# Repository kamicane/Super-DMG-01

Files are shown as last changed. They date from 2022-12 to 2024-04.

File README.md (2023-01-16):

# Super DMG-01

A [KiCad](https://www.kicad.org/) 6.0 recreation of the original Game Boy, with a few modern twists.

One of the main goals of this project is to build an entire DMG using only a DMG CPU or a SGB CPU.

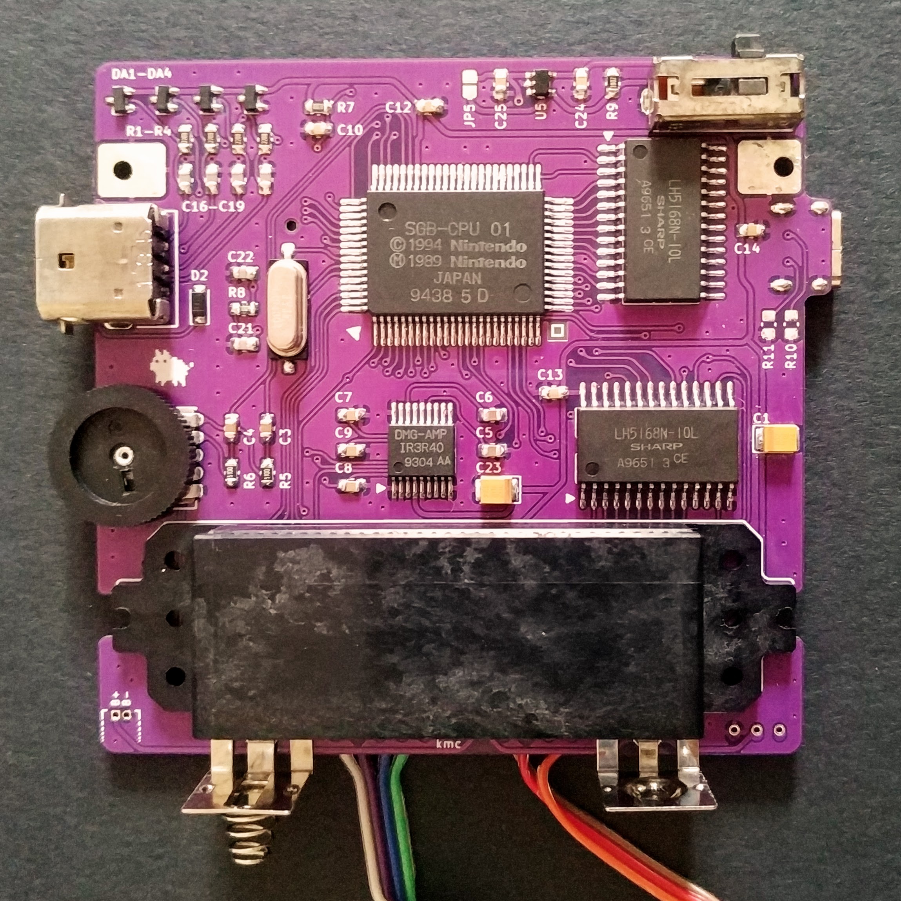
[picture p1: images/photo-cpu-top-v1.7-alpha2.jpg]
pcb-v1.3
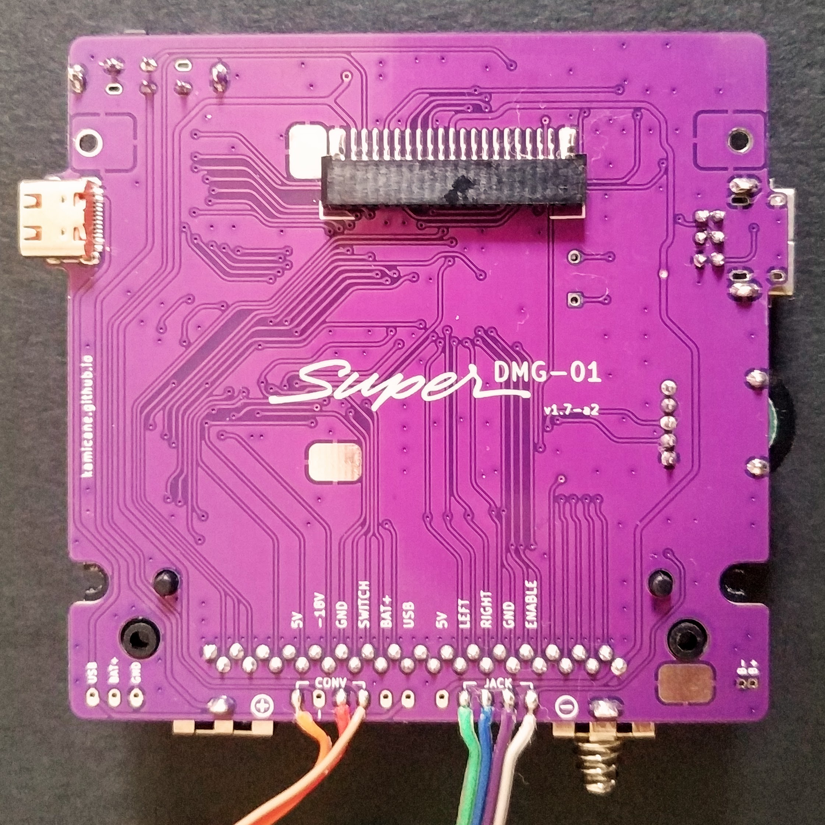
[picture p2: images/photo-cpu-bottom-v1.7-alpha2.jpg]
usb-v1.3
 

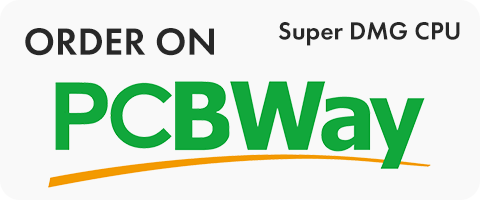
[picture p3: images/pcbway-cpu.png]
pcbw
[](https://www.pcbway.com/QuickOrderOnline.aspx?projectid=13266&issmt=0)
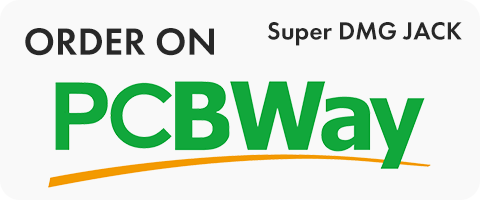
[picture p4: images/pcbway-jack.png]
pcbway
[](https://www.pcbway.com/QuickOrderOnline.aspx?projectid=13350&issmt=0)
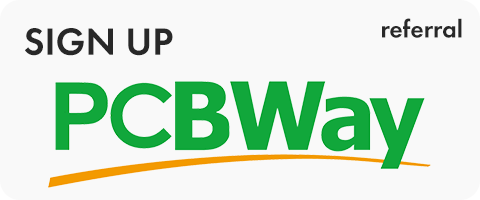
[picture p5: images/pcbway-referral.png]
pcbway
[](https://pcbway.com/g/Gw03Yt)

## Credits

- bit9 for the [DMG schematics](https://imgur.com/a/X5qKI) and [board scans](https://chipmusic.org/forums/post/215957/#p215957)
- [Gekkio](https://github.com/Gekkio) for the CPU, RAM, CART symbols from [Gekkio KiCad libs](https://github.com/Gekkio/gekkio-kicad-libs)
- [Wesk](https://bitbuilt.net/forums/index.php?members/wesk.1486/) for [these amazing DMG shell scans](https://bitbuilt.net/forums/index.php?threads/dmg-gameboy-scan.4479/), which allow me to do all sort of adapters and covers and whatnot, and test the pcb fitment virtually

## Boards

Like an original DMG, the Super DMG-01 is made out of separate boards. Doumentation for each board can be found in the relative sub-folders:

- CPU Board: [Super DMG CPU](super-dmg-cpu)
- JACK Board: [Super DMG JACK](super-dmg-jack)

## 3rd party boards

To complete the game boy additional boards are required:

- DC CONV Board: use [MouseBiteLabs](https://github.com/MouseBiteLabs)' [DMGC-PWR-01](https://github.com/MouseBiteLabs/Game-Boy-DMG-Color/tree/main/DMGC-PWR-01) or use one from a DMG
- LCD Board: Use any of the available IPS kits or use one from a DMG

## Disclaimer

I am not an electronics expert. Super DMG-01 might fry your games, set your house on fire and kill your pets.

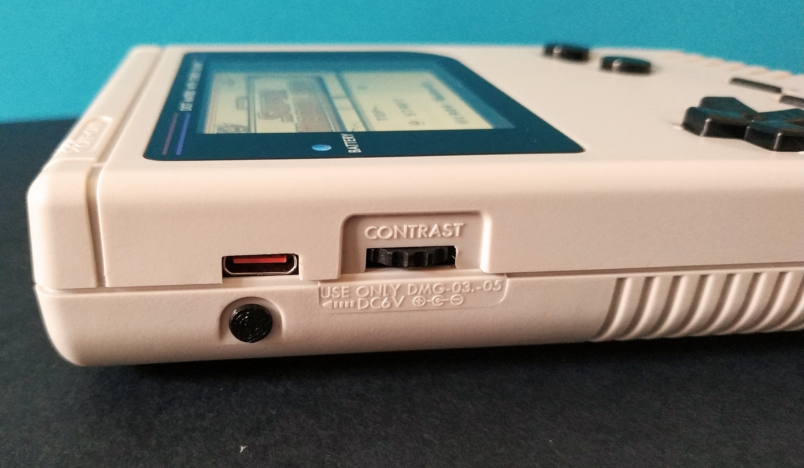
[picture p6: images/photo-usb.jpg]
bottom


## License

This work is licensed under the [Creative Commons Attribution-ShareAlike 4.0 International License.](http://creativecommons.org/licenses/by-sa/4.0/)

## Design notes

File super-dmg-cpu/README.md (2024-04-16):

# Super DMG CPU

Super DMG CPU works with both IPS and DOT MATRIX LCD boards.

top bottom

## Credits

The schematic is largely based on [the work done by bit 9](https://imgur.com/a/X5qKI).

I used [Gekkio KiCAD libs](https://github.com/Gekkio/gekkio-kicad-libs) for a few symbols (cpu, ram, cart connector, link port). The specialized footprints were traced by me using fusion 360, using these [scans by bit 9](https://chipmusic.org/forums/topic/13608/dmg-main-board-schematic-circuit-arduinoboy/) as a reference.

## Warning

v1.8 and below have an error with the Link Port, where the footprint was flipped (sigh). If you have a v1.8 or below please don't use the link port, as it might damage the other Game Boy! This was fixed in later versions.

## Features

### Compatibility

Super DMG CPU can be built using new components, except for the CPU, power switch and link connector. It is also possible to use some components harvested from a DMG.

### USB Type-C

The round power connector is replaced with an USB Type-C port. The port is only connected to a pad on the motherboard, you need to add your own battery charger and/or power regulator if you want to make use of it. This port is optional.

### Power distribution IC

A power distribution IC takes the system load away from the power switch, so the game boy remains fully operational even if the switch is not in an optimal condition. This circuit can be bypassed with a jumper.

### Internal ProSound

The headphone output does not pass through the amplifier, only the volume potentiometer.

## BOM

| Designator | Package | Qty | Value / Description | Source |
|---|---|-----|---|---|
| U1 | QFP-80 14x20 p0.8 | 1 | CPU | DMG, SGB
| U2 | SOP-28 17.5x8.4 p1.27 | 1 | VRAM | DMG, SGB, [LCSC](https://lcsc.com/product-detail/C1351073.html)
| U3 | SOP-28 17.5x8.4 p1.27 | 1 | RAM | DMG, SGB, [LCSC](https://lcsc.com/product-detail/C1351073.html)
| U4 | SSOP-18 6x7.4 p0.8 | 1 | Audio Amplifier | DMG
| EXT1 | | 1 | Link Connector | DMG
| DA1, DA2, DA3, DA4 | SOT-23-3 | 4 | BAV99-7-F | [LCSC](https://www.lcsc.com/product-detail/C106919.html)
| C1, C23 | 3528 | 2 | 100µf tantalum | [LCSC](https://lcsc.com/product-detail/C122271.html)
| SW1 | | 1 | Power Switch | DMG
| U5 | SOT-23-5 | 1 | Power Distribution | [LCSC](https://lcsc.com/product-detail/C517266.html)
| D2 | SOD-123 | 1 | 1N414 | [LCSC](https://lcsc.com/product-detail/C83528.html)
| X1 | HC-49S | 1 | 4.194304 MHz | DMG, [LCSC (TH)](https://lcsc.com/product-detail/C718646.html), [LCSC (SMD)](https://lcsc.com/product-detail/C2149317.html)
| USB1 | USB_C_16p | 1 | Charge Connector | [LCSC](https://lcsc.com/product-detail/C2931472.html)
| VR1 | | 1 | Volume Pot | DMG, [AliExpress](https://www.aliexpress.com/item/32840044311.html)
| CN1 | 1.25 x 21 SMD | 1 | LCD Board Connector | DMG, [AliExpress](https://www.aliexpress.com/item/1005005484837763.html)
| CN2 |  | 1 | Cart Connector | DMG, [AliExpress](https://www.aliexpress.com/item/1005002719771295.html)
| CN3 | | 1 | AA Battery Contacts | DMG, [AliExpress](https://www.aliexpress.com/item/32801068366.html)
| CN4 | 1.25 TH | 1 | Lipo Battery Connector | [LCSC](https://www.lcsc.com/product-detail/C722595.html)
| C3, C4 | 0805 | 2 | 1µF |
| C5, C6 | 0805 | 2 | 10µF |
| C7, C8, C9 | 0805 | 3 | 47nF |
| C10, C24, C25 | 0805 | 3 | 100nF |
| C12, C13, C14 | 0805 | 3 | 10nF |
| C16, C17, C18, C19 | 0805| 4 | 100pF |
| C21, C22 | 0805 | 2 | 27pF |
| R1, R2, R3, R4 | 0805 | 4 | 220Ω|
| R5, R6 | 0805 | 2 | 510Ω |
| R7 | 0805 | 1 | 180kΩ |
| R8 | 0805 | 1 | 1MΩ |
| R9 | 0805 | 1 | 10kΩ |
| R10, R11 | 0805 | 2 | 5.1kΩ |

## Assembly

- Solder all SMD components on the front side
- If using a power board with integrated power distribution close ```J5``` and do not install ```U5```, ```C24```, ```C25```, ```R9```
- If using an external amplifier, such as [Super DMG JACK](../super-dmg-jack) do not install ```U4```, ```C5-C9```, ```C23```
- If you do not need link functionality you can omit ```EXT1```, ```DA1-DA4```, ```R1-R4```, ```C16-C19```, ```D2```
- Solder the through hole components and the LCD board connector
- (Optional) solder the usb connector and cut an opening for the usb port in the front shell using the provided [rudimentary jig](../3d_models/dmg_usbc_jig.stl)
- The original DC jack hole can be covered with this simple [3d printed plug](../3d_models/dmg_dc_plug.stl)

## Notes

If using an original LCD board you need an original *DMG DC CONV* voltage regulator, as acceptable modern replacements that also include the -18v rail *do not exist yet*.

This pcb cannot be easily biverted yet.

## Ordering

[pcbway](https://www.pcbway.com/QuickOrderOnline.aspx?projectid=13266&issmt=0)
[pcbway](https://pcbway.com/g/Gw03Yt)

Make sure you order with 1.0mm thickness.

## License

This work is licensed under the [Creative Commons Attribution-ShareAlike 4.0 International License.](http://creativecommons.org/licenses/by-sa/4.0/)

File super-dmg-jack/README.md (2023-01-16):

# Super DMG JACK

Super DMG JACK is a replacement headphone/audio PCB for the original Game Boy. It can be used on a stock DMG or the Super DMG-01.

It uses a PAM8302 mono amplifier to power the speaker when no headphones are present, but it can also be built as a headphone jack replacement using the amplifier on the CPU board.

The amplifier schematic is based on [Adafruit's pam8302 amplifier PCB](https://github.com/adafruit/Adafruit-PAM8302-Mono-Amplifier-PCB).

The headphone output needs to be unamplified, and grabbed _after_ the DMG volume potentiometer.

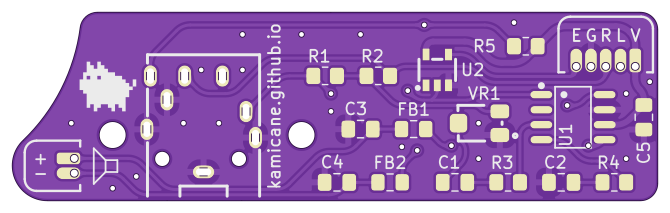
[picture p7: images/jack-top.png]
sdmg jack top
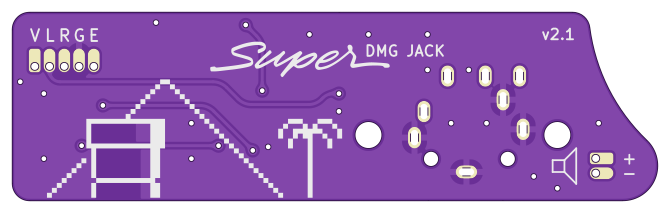
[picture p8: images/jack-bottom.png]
sdmg jack bottom
 

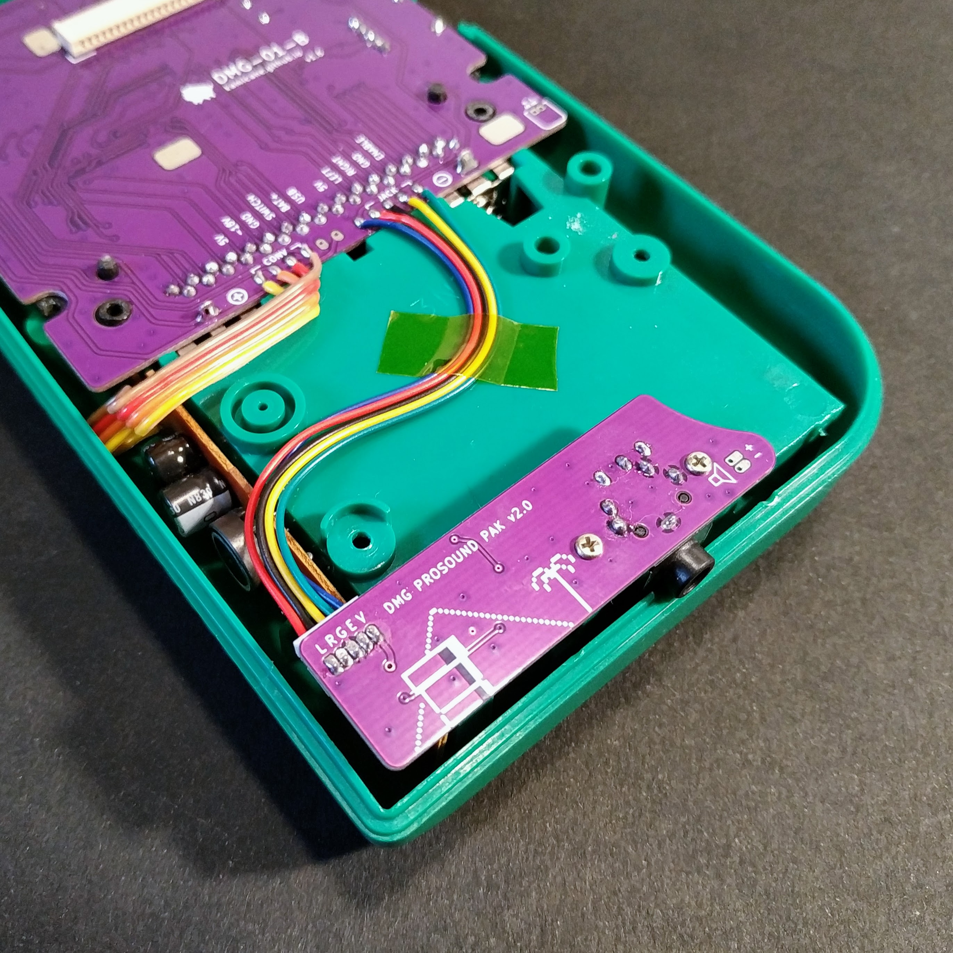
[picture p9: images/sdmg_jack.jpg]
sdmg jack
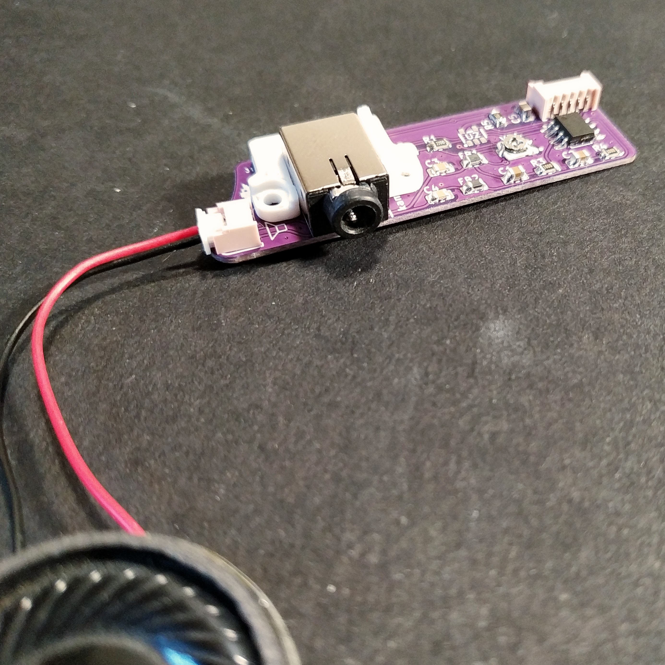
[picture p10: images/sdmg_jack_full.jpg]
sdmg jack full
 

## BOM

| Designator | Package | Qty | Value / Description | Source |
|---|---|-----|---|---|
| CN1 | PJ-3043-B | 1 | Headphone connector | [LCSC](https://lcsc.com/product-detail/C2682182.html) |
| CN2 | 1.25 TH | 1 | CPU PCB Connector | [LCSC](https://lcsc.com/product-detail/C722595.html) |
| CN3 | 1.25 TH | 1 | Speaker Connector | [LCSC](https://lcsc.com/product-detail/C722604.html) |
| U1 | SOP-8 | 1 | PAM8302 | [LCSC](https://lcsc.com/product-detail/C112137.html) |
| U2 | SOT-23-5 | 1 | SN74AHC1G14 | [LCSC](https://lcsc.com/product-detail/C7469.html) |
| VR1 | Bourns TC33X-2-103E | 1 | 10kΩ SMD | [LCSC](https://lcsc.com/product-detail/C719176.html) |
| FB1, FB2 | 0805 | 2 | Ferrite Bead ||
| C1, C2, C5 | 0805 | 3 | 1µf ||
| C3, C4 | 0805 | 3 | 220pf ||
| R1, R2 | 0805 | 2 | 220Ω ||
| R3, R4 | 0805 | 2 | 100Ω ||
| R5 | 0805 | 1 | 10kΩ ||

I got premade wires from [AliExpress](https://www.aliexpress.com/item/1005002353691025.html) (1.25mm 2p and 5p), but you can also just use 28/30 awg without connectors.

I use "WSC" 8Ω 2W speakers from AliExpress.

## DMG Pinout

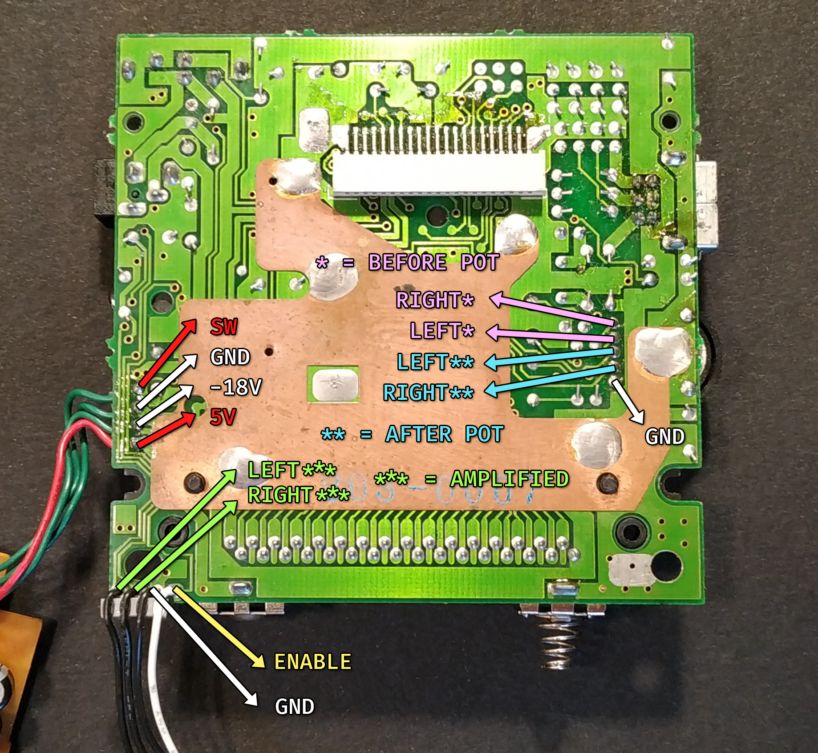
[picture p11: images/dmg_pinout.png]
dmg-pinout


## Full Installation

Important: do not solder ```U2``` and/or do not wire the (E)nable signal. The speaker must be connected to this board.

- Solder the SMD components
- Solder the through hole components
- On the stock DMG solder the L/R signals to the volume potentiometer (** after pot), on Super DMG-01 solder to the bottom pads directly
- Get power from the 5v rail on the CPU board
- Adjust the trimpot

### Trimpot notes

Adjust the trimpot to reduce the power draw and max volume of the amplifier. Boot the DMG at minimum volume, and slowly turn it up, while also adjusting the trimpot. The Game Boy will shut down if you're drawing too much power.
Do the final trimpot adjustment once the DMG volume is at its maximum value.

The final maximum volume will depend on the batteries and the voltage regulator you're using.

## Jack-only Installation

The jack-only installation is meant to be used with the on-board DMG amplifier, however you still need to solder an extra wire for power as the ENABLE signal needs to be inverted.

Important: solder only ```U2```, ```R5```, the headphone jack and the CPU PCB connector. The speaker must be kept in the LCD board.

- Solder the SMD components
- Solder the through hole components
- On the stock DMG solder the L/R signals to the volume potentiometer (** after pot), on Super DMG-01 solder to the bottom pads directly
- Get power from 5V (Super DMG CPU) or SW (stock DMG) on the CPU board

## Notes

3d print the [jack spacer](../3d_models/super_dmg_jack_spacer.stl) for correct alignment.

## Ordering

[pcbway](https://www.pcbway.com/QuickOrderOnline.aspx?projectid=13350&issmt=0)
[pcbway](https://pcbway.com/g/Gw03Yt)

Make sure you order in 1.0mm thickness.

## License

This work is licensed under the [Creative Commons Attribution-ShareAlike 4.0 International License.](http://creativecommons.org/licenses/by-sa/4.0/)

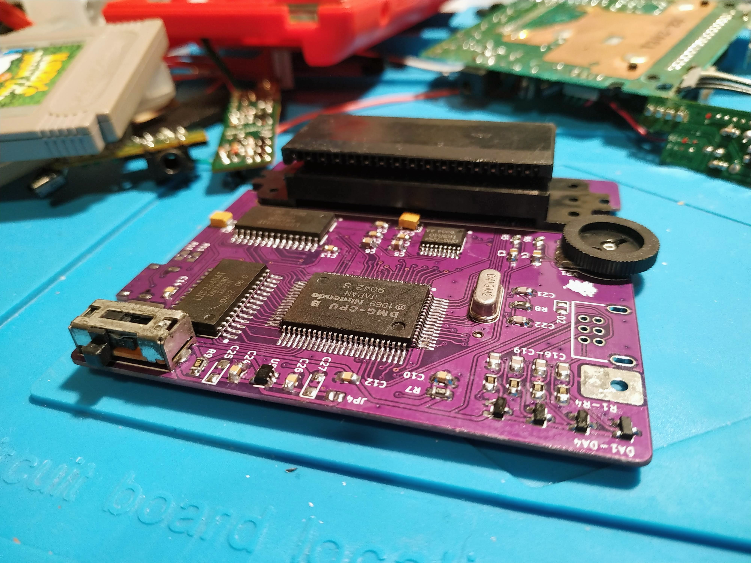
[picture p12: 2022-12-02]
images/pcb-v1.3.jpg

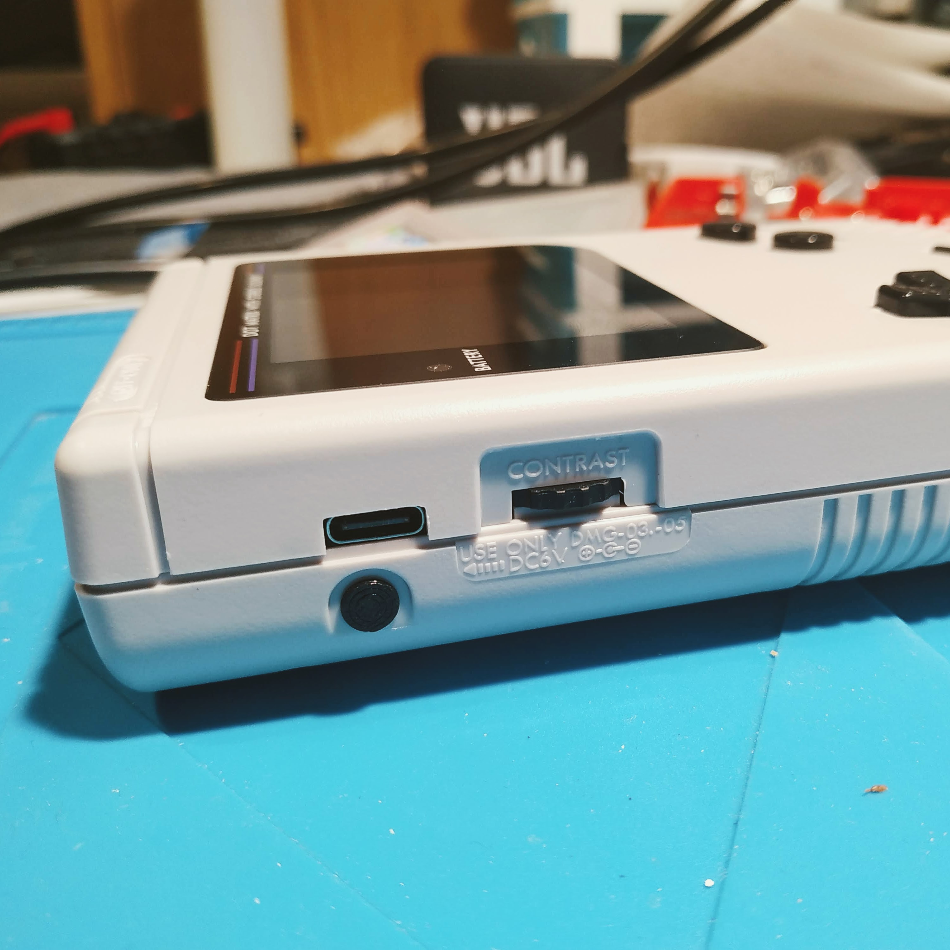
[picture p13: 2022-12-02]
images/usb-v1.3.jpg

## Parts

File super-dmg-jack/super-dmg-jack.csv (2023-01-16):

Comment | Designator | Footprint | LCSC
1µf | C1,C2,C5 | Capacitor_SMD:C_0805_2012Metric_Pad1.18x1.45mm_HandSolder
220pf | C3,C4 | Capacitor_SMD:C_0805_2012Metric_Pad1.18x1.45mm_HandSolder
PJ-3043-B | CN1 | easyeda2kicad:AUDIO-TH_PJ-3043-B | C2682182
DMGB_AUDIO_HEADER | CN2 | kmc_lib:CONN-TH_5P-P1.25_LONGPADS | C722604
Speaker | CN3 | kmc_lib:CONN-TH_2P-P1.25_HCTL_HC-1.25-2AW_LONGPADS | C722595
FerriteBead_Small | FB1,FB2 | Inductor_SMD:L_0805_2012Metric_Pad1.15x1.40mm_HandSolder
220Ω | R1,R2 | Resistor_SMD:R_0805_2012Metric_Pad1.20x1.40mm_HandSolder
100Ω | R3,R4 | Resistor_SMD:R_0805_2012Metric_Pad1.20x1.40mm_HandSolder
10kΩ | R5 | Resistor_SMD:R_0805_2012Metric_Pad1.20x1.40mm_HandSolder
PAM8302AADCR | U1 | easyeda2kicad:SOP-8_L4.9-W3.9-P1.27-LS6.0-BL | C112137
SN74AHC1G14DBVR | U2 | easyeda2kicad:SOT-23-5_L3.0-W1.7-P0.95-LS2.8-BR | C7469
TC33X-2-103E | VR1 | easyeda2kicad:RES-ADJ-SMD_3P-L3.0-W3.8-P1.75-BR | C719176

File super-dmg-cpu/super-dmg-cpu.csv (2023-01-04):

Comment | Designator | Footprint | LCSC
100µf | C1,C23 | Capacitor_Tantalum_SMD:CP_EIA-3528-12_Kemet-T_Pad1.50x2.35mm_HandSolder | C122271
100nF | C10,C24,C25 | Capacitor_SMD:C_0805_2012Metric_Pad1.18x1.45mm_HandSolder | C49678
10nF | C12,C13,C14 | Capacitor_SMD:C_0805_2012Metric_Pad1.18x1.45mm_HandSolder | C1710
100pF | C16,C17,C18,C19 | Capacitor_SMD:C_0805_2012Metric_Pad1.18x1.45mm_HandSolder | C1790
27pF | C21,C22 | Capacitor_SMD:C_0805_2012Metric_Pad1.18x1.45mm_HandSolder | C527182
1µF | C3,C4 | Capacitor_SMD:C_0805_2012Metric_Pad1.18x1.45mm_HandSolder | C28323
10µF | C5,C6 | Capacitor_SMD:C_0805_2012Metric_Pad1.18x1.45mm_HandSolder | C15850
47nF | C7,C8,C9 | Capacitor_SMD:C_0805_2012Metric_Pad1.18x1.45mm_HandSolder | C53134
BATTERY | CN4 | easyeda2kicad:CONN-TH_2P-P1.25_HCTL_HC-1.25-2AW | C2845535
1N414 | D2 | Diode_SMD:D_SOD-123 | C83528
BAV99-7-F | DA1,DA2,DA3,DA4 | kmc_lib:SOT-23-3_L2.9-W1.3-P1.90-LS2.4-BR | C106919
220Ω | R1,R2,R3,R4 | Resistor_SMD:R_0805_2012Metric_Pad1.20x1.40mm_HandSolder | C17557
5.1kΩ | R10,R11 | Resistor_SMD:R_0805_2012Metric_Pad1.20x1.40mm_HandSolder | C27834
510Ω | R5,R6 | Resistor_SMD:R_0805_2012Metric_Pad1.20x1.40mm_HandSolder | C17734
180kΩ | R7 | Resistor_SMD:R_0805_2012Metric_Pad1.20x1.40mm_HandSolder | C17501
1MΩ | R8 | Resistor_SMD:R_0805_2012Metric_Pad1.20x1.40mm_HandSolder | C17514
10kΩ | R9 | Resistor_SMD:R_0805_2012Metric_Pad1.20x1.40mm_HandSolder | C17414
DPDT | SW1 | kmc_lib:DMGB_POWER_SWITCH | C2848866
LPW5209B5F-21 | U5 | easyeda2kicad:SOT-23-5_L2.9-W1.6-P0.95-LS2.8-BL | C517266
CHARGE_PORT | USB1 | kmc_lib:USB_C_16p | C319148
4.194304 MHz | X1 | dmg_lib:HC-49S | C2149317

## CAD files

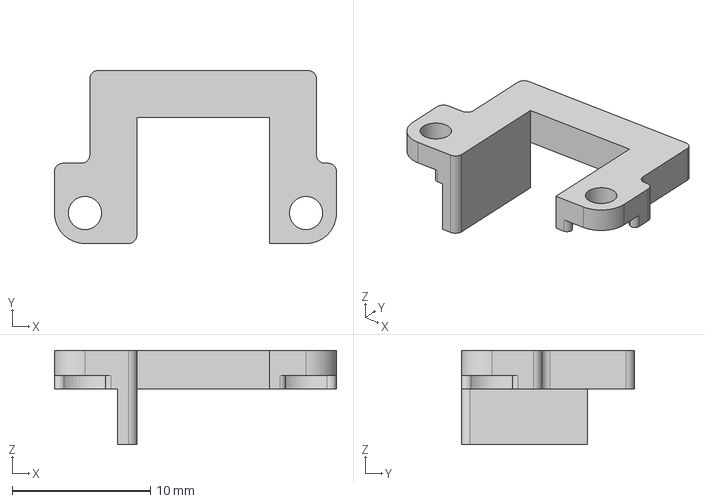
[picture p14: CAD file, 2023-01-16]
3d_models/super_dmg_jack_spacer.step
20.4 x 12.5 x 6.80 mm

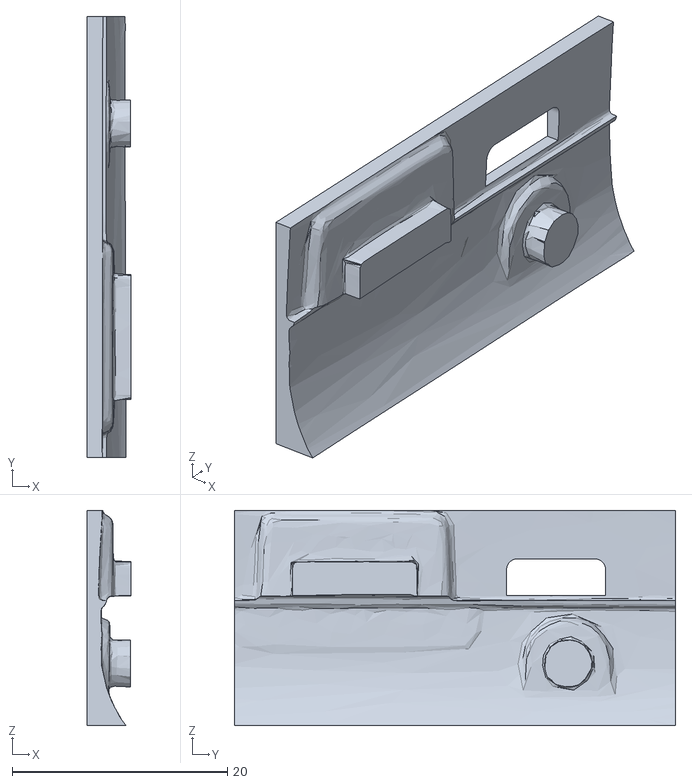
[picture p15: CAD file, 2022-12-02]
3d_models/dmg_usbc_jig.stl
4.12 x 41.0 x 20.0

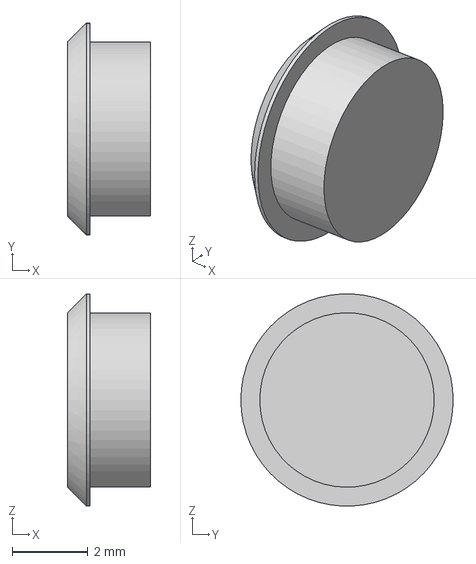
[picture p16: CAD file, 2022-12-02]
3d_models/dmg_dc_plug.step
2.20 x 5.60 x 5.59 mm

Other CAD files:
3d_models/dmg_dc_plug.stl
3d_models/super_dmg_jack_spacer.stl

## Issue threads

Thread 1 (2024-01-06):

Fix port Link ?

Neorad1870, 2024-01-06:
Hello, I would like to know if a solution would be possible to correct the communication port? with track cut? welding ? I have version 1.8r, thank you

rapiqui, 2024-01-23:
Hi, perhaps a thin intermediate pcb with wire rerouting? I am in the same situation. Thanks!

Neorad1870, 2024-01-23:
Super GameBoy Link Port by qwertymodo on Tindietindie.comJoão ***@***.***+41 76 405 17 36Le 23 janv. 2024 à 16:57, rapiqui ***@***.***> a écrit :Hi, perhaps a thin intermediate pcb with wire rerouting? I am in the same situation. Thanks!

EthanChinCN, 2024-01-24:
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

credit to zipplet from gameboy discord server.

explit7, 2024-05-18:
Hm, i also have 1.8R Mainboard. I will simply solder 6x 90degree pins. A simple adapter could be made externally.
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

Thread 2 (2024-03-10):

LCD board connector no longer available from link

Q-Bert-Reynolds, 2024-03-10:
[The LCD connector Ali Express link in the build of materials](https://github.com/kamicane/Super-DMG-01/blob/e557c3cb3f4540ce3f1007be29782819fd7b3acc/super-dmg-cpu/README.md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) is dead. Almost felt like I caused it. It wasn't dead until after I ordered a few and nothing came. I've been looking for another source, but I've had no such luck.

Q-Bert-Reynolds, 2024-03-13:
I found a potentially suitable replacement for the [LCD board connector here](https://www.aliexpress.us/item/3256805298523011.html). They have an option for a 21 pin FPC connector with 1.25mm spacing that looks the part. I'm ordering a few now. I'll let you know how it goes.

On a related note, I found an okay-ish replacement for the [power switch from Mouser](https://www.mouser.com/ProductDetail/CK/SK22F02G6?qs=Gufeu08L/l3k5gmurXhV/g%3D%3D). It has the same footprint, but it requires quite a bit of trimming to fit - removing two of the pins, shortening the metal housing by 3mm or so, and shaving down the plastic slide so that it can fit in the switch cover plate thing. Still looking for a low profile version though.

kamicane, 2024-03-21:
> I found a potentially suitable replacement for the [LCD board connector here](https://www.aliexpress.us/item/3256805298523011.html). They have an option for a 21 pin FPC connector with 1.25mm spacing that looks the part. I'm ordering a few now. I'll let you know how it goes.

Amazing!

As for the power switch another idea could be finding a smaller one and making a 3d printed replacement part to fit it in the shell. Should be fine as long as it lines up somewhat.

Q-Bert-Reynolds, 2024-04-15:
Completely forgot to follow up. I can confirm that the connector they sent fits and works.

kamicane, 2024-04-16:
Updated the link, thanks!

explit7, 2024-06-06:
Unfortunately they don't ship to Germany, maybe to some other countries also.
 https://www.aliexpress.us/item/3256805298523011.html

If you find another seller, who sells the display connector - it would be really cool!

itavero, 2024-12-31:
@explit7 Did you find a supplier yet? Also looking for these and the provided links do not work for me in the Netherlands.

explit7, 2024-12-31:
> @explit7 Did you find a supplier yet? Also looking for these and the provided links do not work for me in the Netherlands.

Unfortunately not. I had to sacrifice a Mainboard in bad condition. for me the links also not work anymore... :(

Closed 2024-04-16.

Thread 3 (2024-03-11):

audio amplifier assembly on original dmg

Neorad1870, 2024-03-11:
hello, would it be possible to have a photo of the assembly concerning the audio amplifier on an original dmg, I do not fully understand the explanations, thank you

kamicane, 2024-03-21:
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

Install only the circled components and keep the speaker in the LCD board. That's it.

Closed 2024-03-21.

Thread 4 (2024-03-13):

[Feature Request] Support GBC-style link ports

Q-Bert-Reynolds, 2024-03-13:
DMG link ports can only be harvested from other DMGs. GBC/GBP/GBA link ports, on the other hand, are readily available from [all](https://catskullelectronics.com/products/gba-gbc-link-port) [sorts](https://www.aliexpress.us/item/3256803930669143.html?spm=a2g0o.productlist.main.105.6537507aqybNks) of [places](https://retrogamerepairshop.com/products/link-cable-replacement-port-for-gbc-gbp-gbl?variant=41808976183468), and I'm at least pretty sure there's enough room between the DMG link port pins and the edge of the board to support that footprint.

The only bit that feels a little iffy is how close the GBC link port housing through holes would be to the DMG link port ones, but I feel pretty confident they could be omitted and the GBC link port housing pins could just be bent out to fit. Here's a crude drawing:
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

This addition would bring this project one step closer to helping people build functioning DMGs without harvesting a single DMG part. Thank you for your consideration.

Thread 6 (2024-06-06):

Populated C5-C9, C23 when using Super DMG-Jack. Problem or not?

explit7, 2024-06-06:
Its not an issue, rather an question:

I created the latest Version 1.9 on PCBWay, but the guys populated also C5-C9 and C23.
Can it be ignored when i use Super DMG-Jack, or should i desolder this components?

What will happen when i also populate U4?

Than i will have 2x amplifier: One one the mainboard and one on the jack. Would it be a problem?

Maybe you can give a short explanation here @kamicane

Thanks a lot!

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

kamicane, 2024-06-06:
Those extra capacitors should not interfere with the amp on the jack board. You can remove them if you like but it shouldn't be necessary.

If you have the original DMG amp (U4) you can simply install it rather than use the amp on the Super-DMG jack, and do a simple super-dmg jack install without the amp. Do not use both.

[Super-DMG Jack full installation (amp on the jack board)](https://github.com/kamicane/Super-DMG-01/tree/main/super-dmg-jack#full-installation)

[Super-DMG Jack simple installation (original DMG amp on the S/DMG board)](https://github.com/kamicane/Super-DMG-01/tree/main/super-dmg-jack#full-installation)

explit7, 2024-06-07:
Thank you very much for the clarification, @kamicane !

i will leave the capacitors and use the amp in the super-DMG Jack, because its already fully populated.

Closed 2024-06-18.

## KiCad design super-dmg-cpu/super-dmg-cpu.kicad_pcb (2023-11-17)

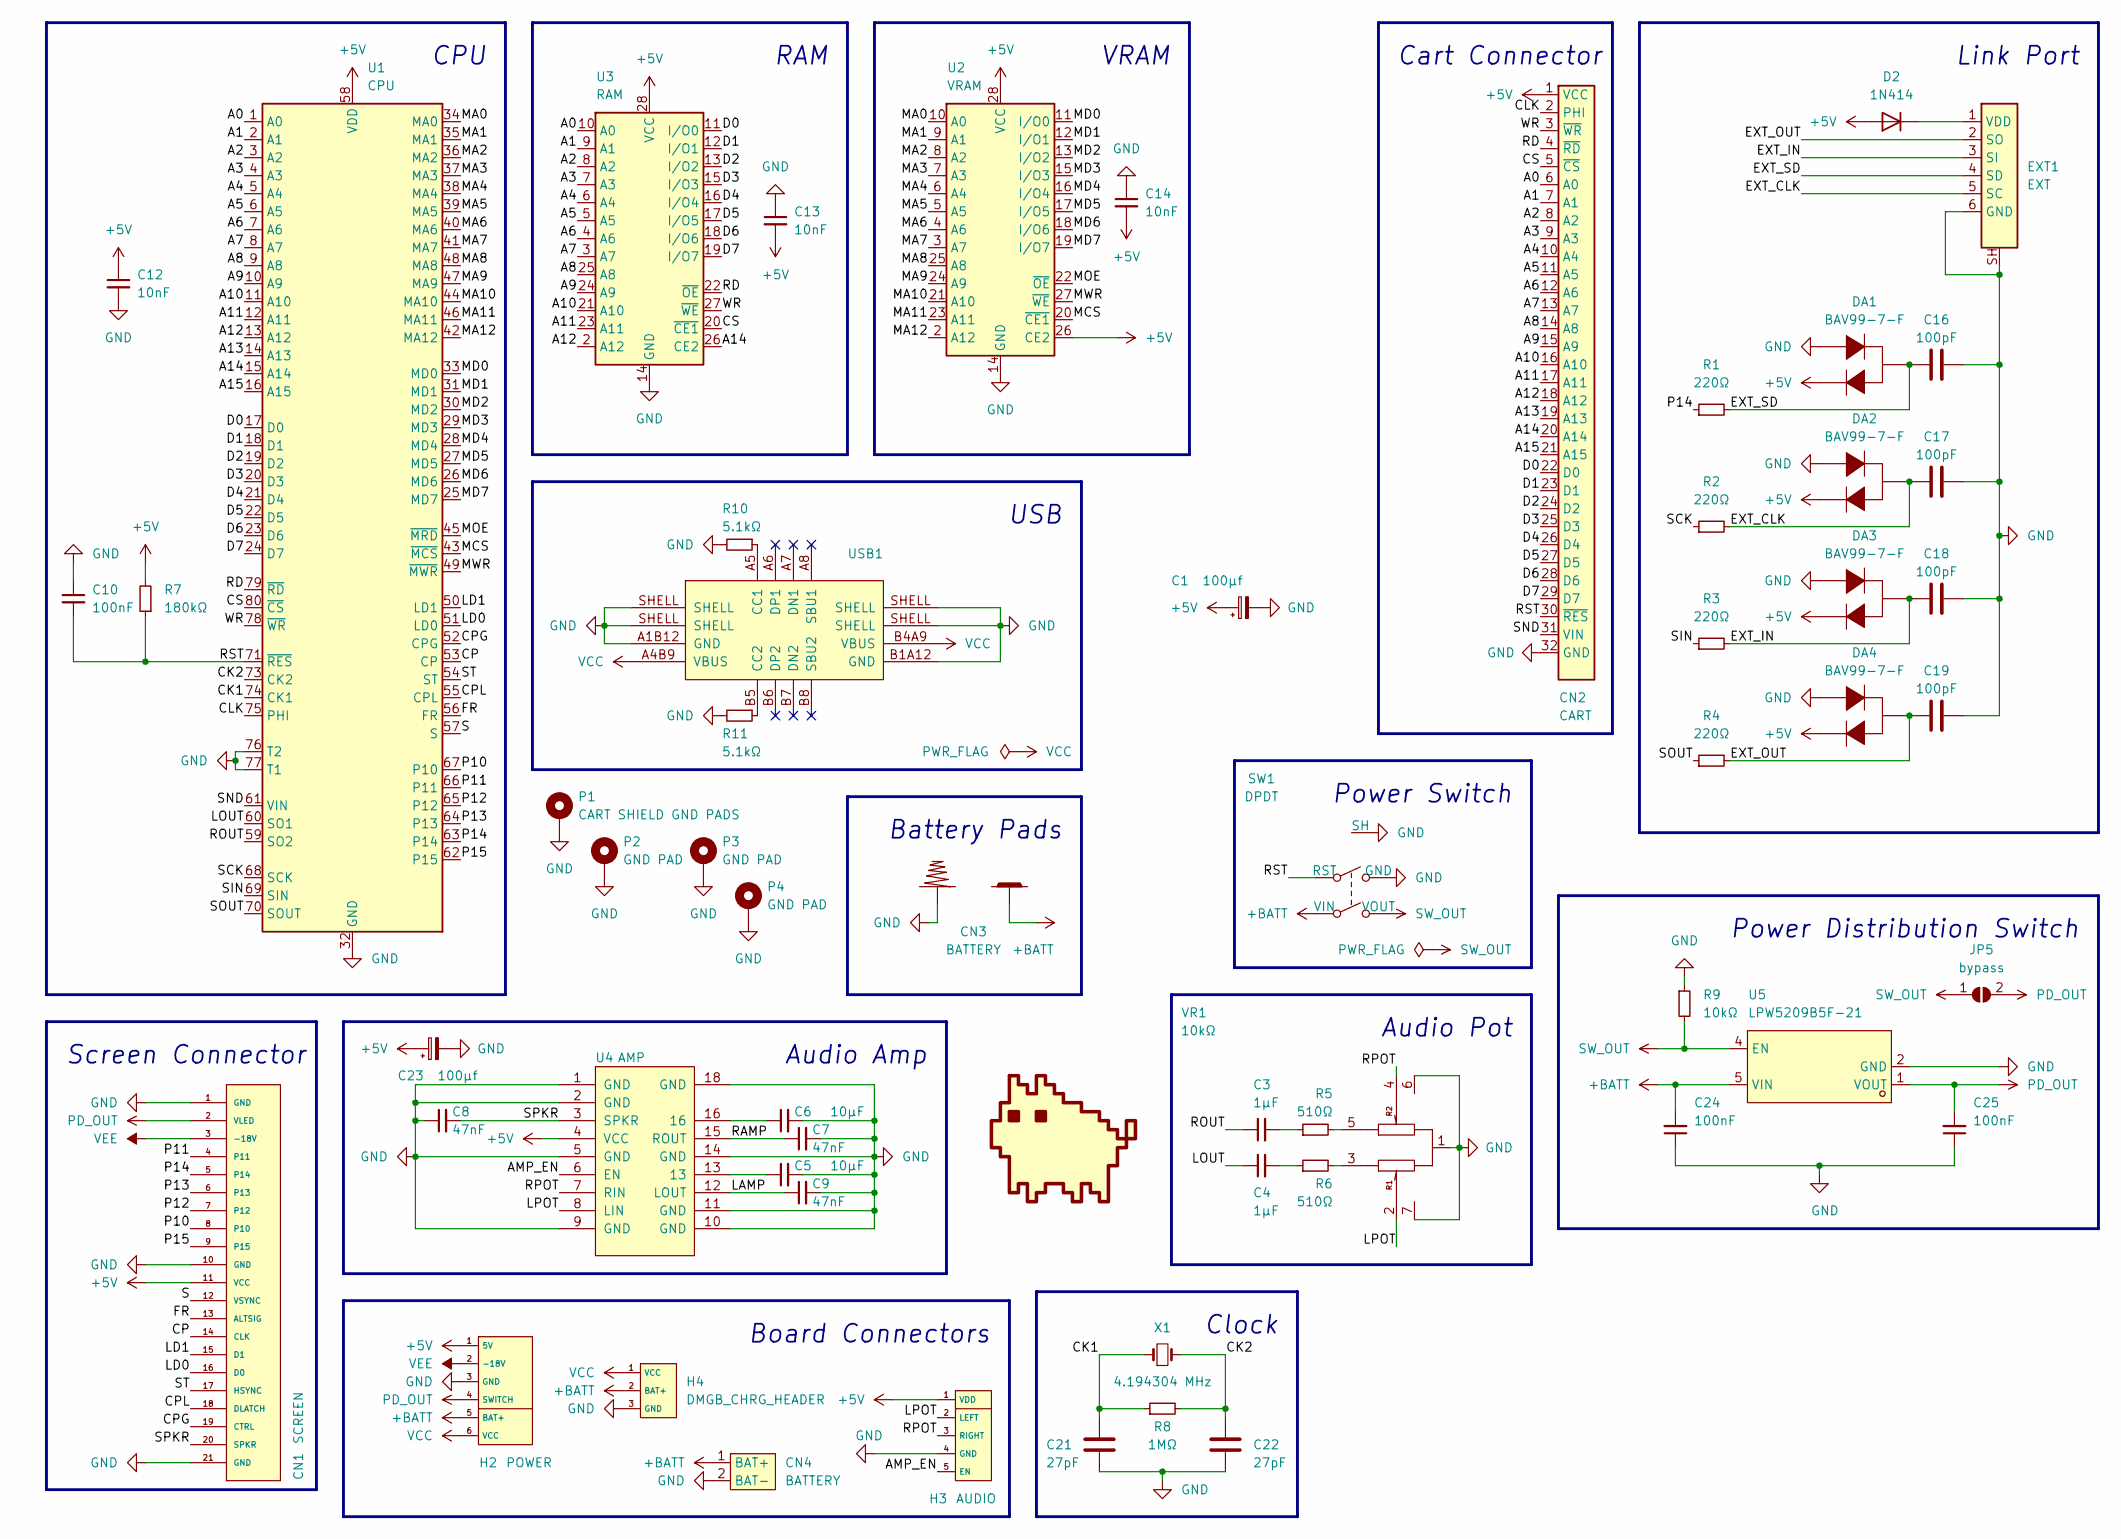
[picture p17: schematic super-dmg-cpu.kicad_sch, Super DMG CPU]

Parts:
C1, C23: 100µf; CP_EIA-3528-12_Kemet-T_Pad1.50x2.35mm_HandSolder; LCSC C122271
C3, C4: 1µF; C_0805_2012Metric_Pad1.18x1.45mm_HandSolder; LCSC C28323
C5, C6: 10µF; C_0805_2012Metric_Pad1.18x1.45mm_HandSolder; LCSC C15850
C7, C8, C9: 47nF; C_0805_2012Metric_Pad1.18x1.45mm_HandSolder; LCSC C53134
C10, C24, C25: 100nF; C_0805_2012Metric_Pad1.18x1.45mm_HandSolder; LCSC C49678
C12, C13, C14: 10nF; C_0805_2012Metric_Pad1.18x1.45mm_HandSolder; LCSC C1710
C16, C17, C18, C19: 100pF; C_0805_2012Metric_Pad1.18x1.45mm_HandSolder; LCSC C1790
C21, C22: 27pF; C_0805_2012Metric_Pad1.18x1.45mm_HandSolder; LCSC C527182
CN1: SCREEN; DMG_FPC_CONN
CN2: CART; DMG_CART_CONN
CN3: BATTERY; DMG_BATTERY_PADS
CN4: BATTERY; CONN-TH_2P-P1.25_HCTL_HC-1.25-2AW; LCSC C2845535
D2: 1N414; D_SOD-123; LCSC C83528
DA1, DA2, DA3, DA4: BAV99-7-F; SOT-23-3_L2.9-W1.3-P1.90-LS2.4-BR; LCSC C106919
EXT1: EXT; DMG_LINK_CONN
G1: kmc; kmc_6mm
H2: POWER; PAD_2.54_HYBRID_X6
H3: AUDIO; PAD_2.54_HYBRID_X5
H4: DMGB_CHRG_HEADER; PAD_2.54_HYBRID_X3
JP5: bypass; solder_jumper_x2
P1: CART SHIELD GND PADS; DMG_CART_SHIELD_CONTACT
P2, P3, P4: GND PAD; DMG_GROUNDPAD
R1, R2, R3, R4: 220Ω; R_0805_2012Metric_Pad1.20x1.40mm_HandSolder; LCSC C17557
R5, R6: 510Ω; R_0805_2012Metric_Pad1.20x1.40mm_HandSolder; LCSC C17734
R7: 180kΩ; R_0805_2012Metric_Pad1.20x1.40mm_HandSolder; LCSC C17501
R8: 1MΩ; R_0805_2012Metric_Pad1.20x1.40mm_HandSolder; LCSC C17514
R9: 10kΩ; R_0805_2012Metric_Pad1.20x1.40mm_HandSolder; LCSC C17414
R10, R11: 5.1kΩ; R_0805_2012Metric_Pad1.20x1.40mm_HandSolder; LCSC C27834
SW1: DPDT; DMGB_POWER_SWITCH; LCSC C2848866
U1: CPU; DMG_CPU
U2: VRAM; DMG_RAM_64K
U3: RAM; DMG_RAM_64K
U4: AMP; DMG_AMP
U5: LPW5209B5F-21; SOT-23-5_L2.9-W1.6-P0.95-LS2.8-BL; JLC Part Extended Part
USB1: CHARGE_PORT; USB_C_16p; LCSC C319148
VR1: 10kΩ; DMG_VOLUME_POT
X1: 4.194304 MHz; HC-49S; LCSC C2149317

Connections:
+5V: C1.1, C12.1, C13.2, C14.2, C23.1, CN1.11 (VCC), CN2.1 (VCC), D2.2 (A), DA1.2 (K), DA2.2 (K), DA3.2 (K), DA4.2 (K), H2.1 (5V), H3.1 (VDD), R7.2, U1.58 (VDD), U2.26 (CE2), U2.28 (VCC), U3.28 (VCC), U4.4 (VCC)
+BATT: C24.2, CN3.1 (+), CN4.1 (BAT+), H2.5 (BAT+), H4.2 (BAT+), SW1.2 (VIN), U5.5 (VIN)
/A0: CN2.6 (A0), U1.1 (A0), U3.10 (A0)
/A1: CN2.7 (A1), U1.2 (A1), U3.9 (A1)
/A2: CN2.8 (A2), U1.3 (A2), U3.8 (A2)
/A3: CN2.9 (A3), U1.4 (A3), U3.7 (A3)
/A4: CN2.10 (A4), U1.5 (A4), U3.6 (A4)
/A5: CN2.11 (A5), U1.6 (A5), U3.5 (A5)
/A6: CN2.12 (A6), U1.7 (A6), U3.4 (A6)
/A7: CN2.13 (A7), U1.8 (A7), U3.3 (A7)
/A8: CN2.14 (A8), U1.9 (A8), U3.25 (A8)
/A9: CN2.15 (A9), U1.10 (A9), U3.24 (A9)
/A10: CN2.16 (A10), U1.11 (A10), U3.21 (A10)
/A11: CN2.17 (A11), U1.12 (A11), U3.23 (A11)
/A12: CN2.18 (A12), U1.13 (A12), U3.2 (A12)
/A13: CN2.19 (A13), U1.14 (A13)
/A14: CN2.20 (A14), U1.15 (A14), U3.26 (CE2)
/A15: CN2.21 (A15), U1.16 (A15)
/AMP_EN: H3.5 (EN), U4.6 (EN)
/CK1: C21.2, R8.1, U1.74 (CK1), X1.1
/CK2: C22.2, R8.2, U1.73 (CK2), X1.2
/CLK: CN2.2 (PHI), U1.75 (PHI)
/CP: CN1.14 (CLK), U1.53 (CP)
/CPG: CN1.19 (CTRL), U1.52 (CPG)
/CPL: CN1.18 (DLATCH), U1.55 (CPL)
/CS: CN2.5 (~CS), U1.80 (~CS), U3.20 (~CE1)
/D0: CN2.22 (D0), U1.17 (D0), U3.11 (I/O0)
/D1: CN2.23 (D1), U1.18 (D1), U3.12 (I/O1)
/D2: CN2.24 (D2), U1.19 (D2), U3.13 (I/O2)
/D3: CN2.25 (D3), U1.20 (D3), U3.15 (I/O3)
/D4: CN2.26 (D4), U1.21 (D4), U3.16 (I/O4)
/D5: CN2.27 (D5), U1.22 (D5), U3.17 (I/O5)
/D6: CN2.28 (D6), U1.23 (D6), U3.18 (I/O6)
/D7: CN2.29 (D7), U1.24 (D7), U3.19 (I/O7)
/EXT_CLK: C17.1, DA2.3 (K), EXT1.5 (SC), R2.2
/EXT_IN: C18.1, DA3.3 (K), EXT1.3 (SI), R3.2
/EXT_OUT: C19.1, DA4.3 (K), EXT1.2 (SO), R4.2
/EXT_SD: C16.1, DA1.3 (K), EXT1.4 (SD), R1.2
/FR: CN1.13 (ALTSIG), U1.56 (FR)
/LAMP: C9.1, U4.12 (LOUT)
/LD0: CN1.16 (D0), U1.51 (LD0)
/LD1: CN1.15 (D1), U1.50 (LD1)
/LOUT: C4.1, U1.60 (SO1)
/LPOT: H3.2 (LEFT), U4.8 (LIN), VR1.2
/MA0: U1.34 (MA0), U2.10 (A0)
/MA1: U1.35 (MA1), U2.9 (A1)
/MA2: U1.36 (MA2), U2.8 (A2)
/MA3: U1.37 (MA3), U2.7 (A3)
/MA4: U1.38 (MA4), U2.6 (A4)
/MA5: U1.39 (MA5), U2.5 (A5)
/MA6: U1.40 (MA6), U2.4 (A6)
/MA7: U1.41 (MA7), U2.3 (A7)
/MA8: U1.48 (MA8), U2.25 (A8)
/MA9: U1.47 (MA9), U2.24 (A9)
/MA10: U1.44 (MA10), U2.21 (A10)
/MA11: U1.46 (MA11), U2.23 (A11)
/MA12: U1.42 (MA12), U2.2 (A12)
/MCS: U1.43 (~MCS), U2.20 (~CE1)
/MD0: U1.33 (MD0), U2.11 (I/O0)
/MD1: U1.31 (MD1), U2.12 (I/O1)
/MD2: U1.30 (MD2), U2.13 (I/O2)
/MD3: U1.29 (MD3), U2.15 (I/O3)
/MD4: U1.28 (MD4), U2.16 (I/O4)
/MD5: U1.27 (MD5), U2.17 (I/O5)
/MD6: U1.26 (MD6), U2.18 (I/O6)
/MD7: U1.25 (MD7), U2.19 (I/O7)
/MOE: U1.45 (~MRD), U2.22 (~OE)
/MWR: U1.49 (~MWR), U2.27 (~WE)
/P10: CN1.8 (P10), U1.67 (P10)
/P11: CN1.4 (P11), U1.66 (P11)
/P12: CN1.7 (P12), U1.65 (P12)
/P13: CN1.6 (P13), U1.64 (P13)
/P14: CN1.5 (P14), R1.1, U1.63 (P14)
/P15: CN1.9 (P15), U1.62 (P15)
/RAMP: C7.1, U4.15 (ROUT)
/RD: CN2.4 (~RD), U1.79 (~RD), U3.22 (~OE)
/ROUT: C3.1, U1.59 (SO2)
/RPOT: H3.3 (RIGHT), U4.7 (RIN), VR1.4
/RST: C10.2, CN2.30 (~RES), R7.1, SW1.5 (RST), U1.71 (~RES)
/S: CN1.12 (VSYNC), U1.57 (S)
/SCK: R2.1, U1.68 (SCK)
/SIN: R3.1, U1.69 (SIN)
/SND: CN2.31 (VIN), U1.61 (VIN)
/SOUT: R4.1, U1.70 (SOUT)
/SPKR: C8.2, CN1.20 (SPKR), U4.3 (SPKR)
/ST: CN1.17 (HSYNC), U1.54 (ST)
/WR: CN2.3 (~WR), U1.78 (~WR), U3.27 (~WE)
GND: C1.2, C5.2, C6.2, C7.2, C8.1, C9.2, C10.1, C12.2, C13.1, C14.1, C16.2, C17.2, C18.2, C19.2, C21.1, C22.1, C23.2, C24.1, C25.1, CN1.1 (GND), CN1.10 (GND), CN1.21 (GND), CN2.32 (GND), CN3.2 (-), CN4.2 (BAT-), DA1.1 (A), DA2.1 (A), DA3.1 (A), DA4.1 (A), EXT1.6 (GND), EXT1.SH, H2.3 (GND), H3.4 (GND), H4.3 (GND), P1.1, P2.1, P3.1, P4.1, R9.1, R10.2, R11.2, SW1.6 (GND), SW1.7 (SH), U1.32 (GND), U1.72 (GND), U1.76 (T2), U1.77 (T1), U2.14 (GND), U3.14 (GND), U4.1 (GND), U4.2 (GND), U4.5 (GND), U4.9 (GND), U4.10 (GND), U4.11 (GND), U4.14 (GND), U4.18 (GND), U5.2 (GND), USB1.A1B12 (GND), USB1.B1A12 (GND), USB1.SHELL, VR1.1, VR1.6 (EH), VR1.7 (EH)
unnamed: C3.2, R5.1
unnamed: C4.2, R6.1
unnamed: C5.1, U4.13
unnamed: C6.1, U4.16
unnamed: D2.1 (K), EXT1.1 (VDD)
unnamed: R5.2, VR1.5
unnamed: R6.2, VR1.3
unnamed: R10.1, USB1.A5 (CC1)
unnamed: R11.1, USB1.B5 (CC2)
PD_OUT: C25.2, CN1.2 (VLED), H2.4 (SWITCH), JP5.2 (B), U5.1 (VOUT)
SW_OUT: JP5.1 (A), R9.2, SW1.1 (VOUT), U5.4 (EN)
VCC: H2.6 (VCC), H4.1 (VCC), USB1.A4B9 (VBUS), USB1.B4A9 (VBUS)
VEE: CN1.3 (-18V), H2.2 (-18V)

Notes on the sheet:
USB
VRAM
Clock
Board Connectors
Power Switch
Battery Pads
Audio Amp
Link Port
Cart Connector
RAM
CPU
Audio Pot
Power Distribution Switch
Screen Connector

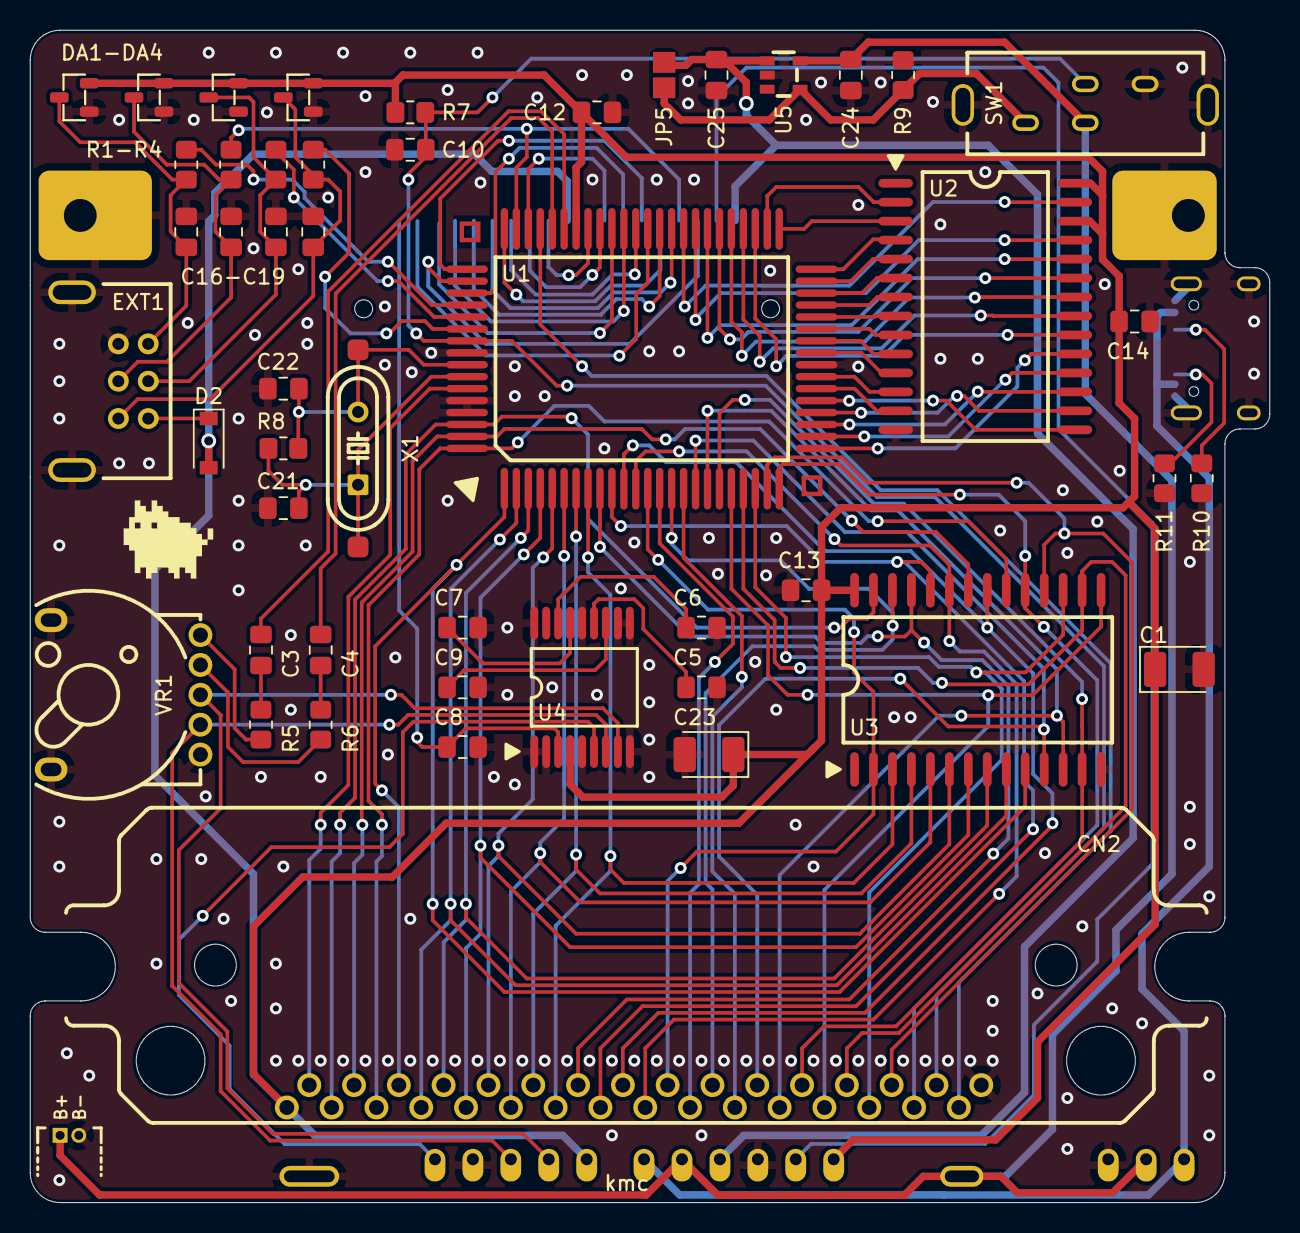
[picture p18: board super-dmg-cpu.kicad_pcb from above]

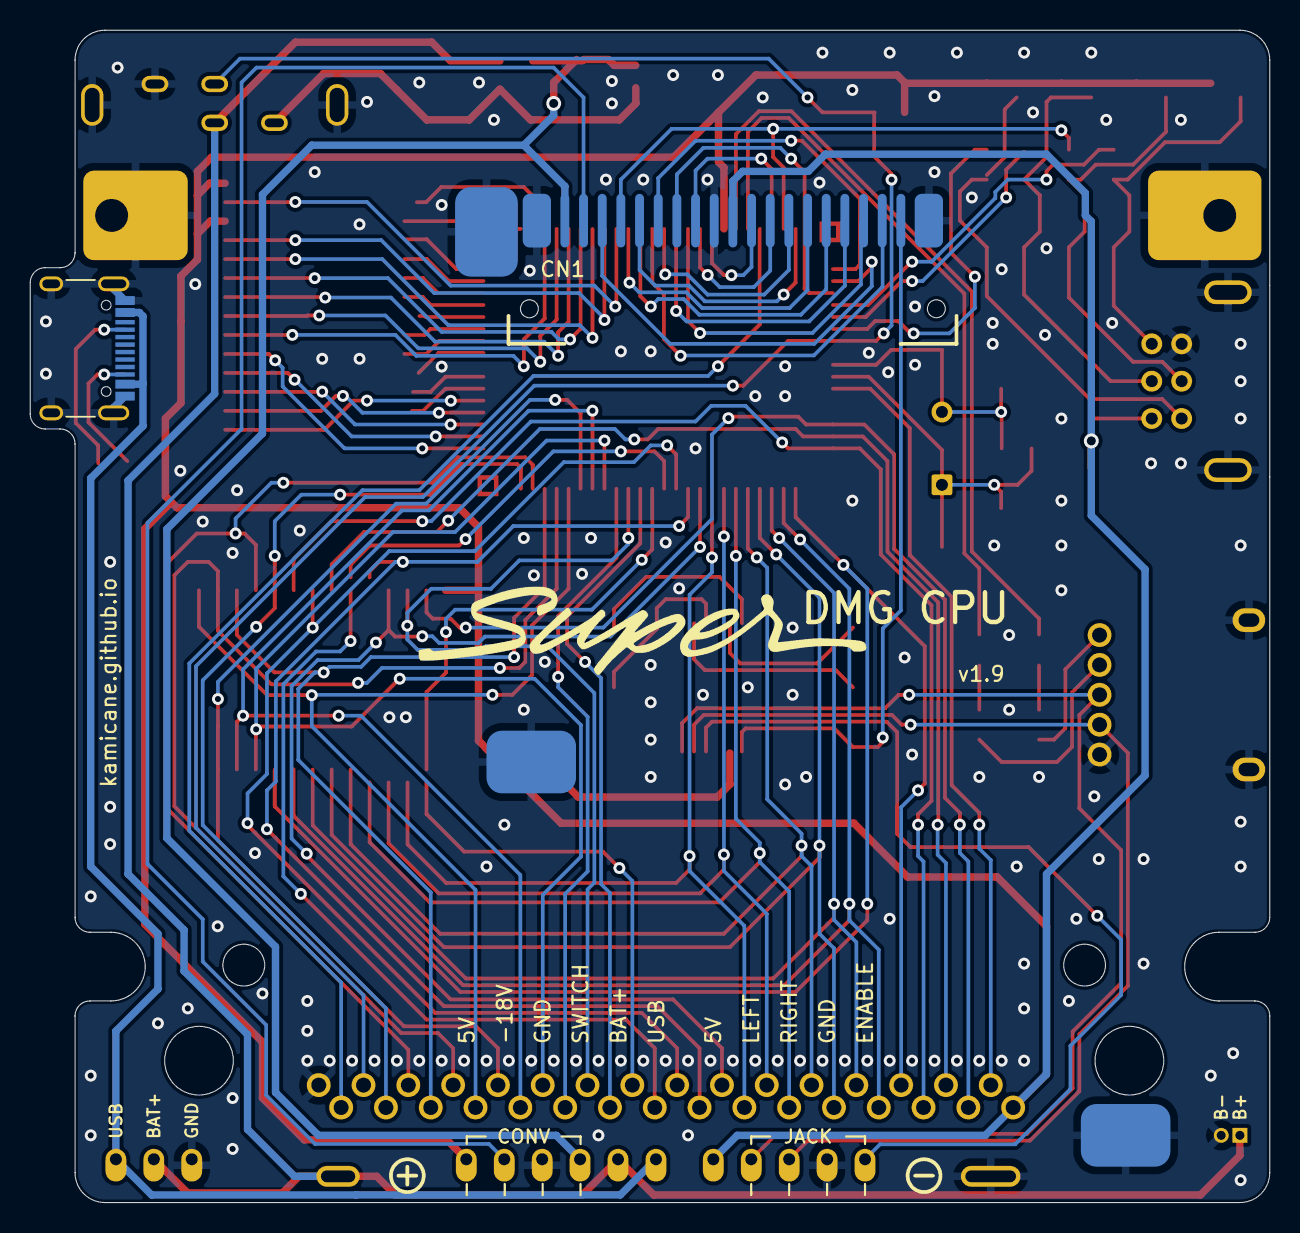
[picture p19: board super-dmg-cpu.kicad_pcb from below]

Board: 2 copper layers, 83.0 x 78.5 mm, 60 parts (8 on the bottom side), 101 nets.

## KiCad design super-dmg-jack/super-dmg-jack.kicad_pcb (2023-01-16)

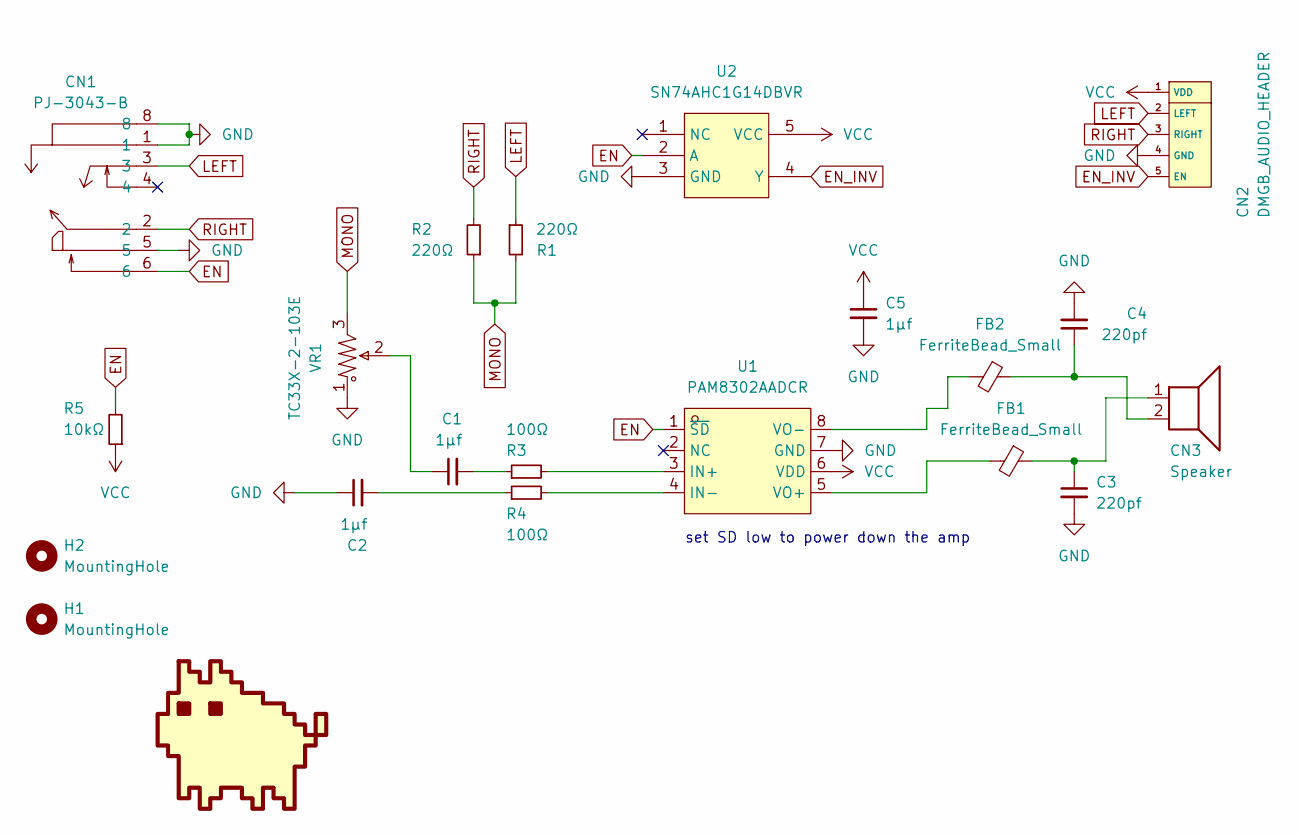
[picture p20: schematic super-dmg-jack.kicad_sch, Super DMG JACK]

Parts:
C1, C2, C5: 1µf; C_0805_2012Metric_Pad1.18x1.45mm_HandSolder
C3, C4: 220pf; C_0805_2012Metric_Pad1.18x1.45mm_HandSolder
CN1: PJ-3043-B; AUDIO-TH_PJ-3043-B; LCSC C2682182
CN2: DMGB_AUDIO_HEADER; CONN-TH_5P-P1.25_LONGPADS; LCSC C722604
CN3: Speaker; CONN-TH_2P-P1.25_HCTL_HC-1.25-2AW_LONGPADS; LCSC C722595
FB1, FB2: FerriteBead_Small; L_0805_2012Metric_Pad1.15x1.40mm_HandSolder
G1: kmc
H1, H2: MountingHole; MountingHole_2.2mm_M2
R1, R2: 220Ω; R_0805_2012Metric_Pad1.20x1.40mm_HandSolder
R3, R4: 100Ω; R_0805_2012Metric_Pad1.20x1.40mm_HandSolder
R5: 10kΩ; R_0805_2012Metric_Pad1.20x1.40mm_HandSolder
U1: PAM8302AADCR; SOP-8_L4.9-W3.9-P1.27-LS6.0-BL; LCSC C112137
U2: SN74AHC1G14DBVR; SOT-23-5_L3.0-W1.7-P0.95-LS2.8-BR; LCSC C7469
VR1: TC33X-2-103E; RES-ADJ-SMD_3P-L3.0-W3.8-P1.75-BR; LCSC C719176

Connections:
EN: CN1.6, R5.2, U1.1 (~SD), U2.2 (A)
EN_INV: CN2.5 (EN), U2.4 (Y)
GND: C2.1, C3.2, C4.2, C5.2, CN1.1, CN1.5, CN1.8, CN2.4 (GND), U1.7 (GND), U2.3 (GND), VR1.1
LEFT: CN1.3, CN2.2 (LEFT), R1.1
MONO: R1.2, R2.1, VR1.3
unnamed: C1.1, VR1.2
unnamed: C1.2, R3.1
unnamed: C2.2, R4.1
unnamed: C3.1, CN3.1, FB1.1
unnamed: C4.1, CN3.2, FB2.1
unnamed: FB1.2, U1.5 (VO+)
unnamed: FB2.2, U1.8 (VO-)
unnamed: R3.2, U1.3 (IN+)
unnamed: R4.2, U1.4 (IN-)
RIGHT: CN1.2, CN2.3 (RIGHT), R2.2
VCC: C5.1, CN2.1 (VDD), R5.1, U1.6 (VDD), U2.5 (VCC)

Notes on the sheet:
set SD low to power down the amp

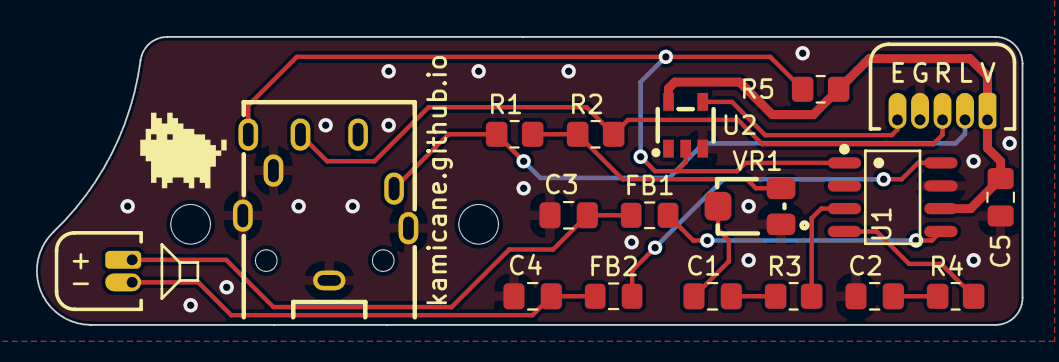
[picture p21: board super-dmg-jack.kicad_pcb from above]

Board: 2 copper layers, 54.8 x 16.0 mm, 21 parts (0 on the bottom side), 16 nets.

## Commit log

2022-10-04 add images
    [dmg-01-b.kicad_pcb]
2022-10-05 removed kicad_prl
2022-11-27 - fix c23 orientation - fix d2 footprint - minor silkscreen changes
    [dmg-01-b.kicad_pcb, dmg-01-b.kicad_sch]
2022-11-27 remove extra power distribution switch capacitors since they were not needed
    [dmg-01-b.kicad_pcb, dmg-01-b.kicad_sch]
2022-11-28 update images
    [dmg-01-b.kicad_pcb, dmg-01-b.kicad_sch]
2022-11-28 remove unused SPKR pad clean up bottom area add optional jst style connectors
    [dmg-01-b.kicad_pcb, dmg-01-b.kicad_sch]
2022-12-01 test connectors (for history, to be removed)
    [dmg-01-b.kicad_pcb, dmg-01-b.kicad_sch]
2022-12-02 fixed battery connector (!) less stupid routing in some areas minor changes
    [dmg-01-b.kicad_pcb, dmg-01-b.kicad_sch]
2022-12-02 pass DRC with roundtracks at 0.6
    [dmg-01-b.kicad_pcb]
2022-12-02 add basic BOM with LCSC parts
    [dmg-01-b.csv, dmg-01-b.kicad_sch, dmg_dc_plug.step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]
2022-12-02 README, add pcbdraw style, update images
2022-12-03 significantly simplified the power stuff
    [dmg-01-b.kicad_pcb, dmg-01-b.kicad_sch]
2022-12-03 ignore autogenerated rounded board
2022-12-03 minor tracks cleanup
    [dmg-01-b.kicad_pcb, dmg-01-b.kicad_sch]
2022-12-05 change side of 5v pin on the audio header
    [dmg-01-b.kicad_pcb, dmg-01-b.kicad_sch]
2022-12-06 more pedantic changes
    [dmg-01-b.kicad_pcb, dmg-01-b.kicad_sch]
2022-12-15 better bottom pads
    - more clearance between the battery terminals and bottom pads
    - swapped +bat and usb on the power pads because it makes more sense
    - marked more clearly where the og boards go
    - small routing optimizations
    - small cosmetic changes
    [dmg-01-b.kicad_pcb, dmg-01-b.kicad_sch]
2023-01-04 Version 1.7 - Rebranding - Fix AA negative battery contact - Add charger pads - Made the power switch footprint compatible with a 3rd party switch - Add experimental JACK board - PCBWaaaaaaaaaaaaaaaa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
    [dmg-01-b.kicad_pcb, super-dmg-cpu.csv, super-dmg-cpu.kicad_pcb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]
2023-01-04 sub-boards clarification
2023-01-09 remove link to incompatible power switch :(
2023-01-16 Jack: README, prepare for release - images - minor cosmetic changes
    [super-dmg-jack.csv, super-dmg-jack.kicad_pcb, super-dmg-jack.kicad_sch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]
2023-01-16 CPU: fix inverted L/R pins
    [super-dmg-cpu.kicad_pcb, super-dmg-cpu.kicad_sch]
2023-01-16 CPU: remove unused pads on the power switch
    [super-dmg-cpu.kicad_pcb, super-dmg-cpu.kicad_sch]
2023-01-16 CPU: clean up for DRC
    [super-dmg-cpu.kicad_pcb]
2023-01-16 JACK: clean up for DRC
    [super-dmg-jack.kicad_pcb]
2023-01-16 jack: add pcbway links
2023-01-16 CPU: update pcb 2d images
2023-11-16 Fixed the link port - The link port footprint was flipped
    [super-dmg-cpu.kicad_pcb, super-dmg-cpu.kicad_sch]
2023-11-16 finished preliminary update to kicad 7
    [super-dmg-cpu.kicad_pcb]
2023-11-17 preparing for gerbers release
    [super-dmg-cpu.kicad_pcb]
2024-04-16 alternative lcd board connector
